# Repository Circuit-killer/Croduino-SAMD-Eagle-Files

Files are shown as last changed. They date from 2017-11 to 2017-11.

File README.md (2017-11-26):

# Croduino SAMD Eagle Files
## Image
will be available soon

## Description and details
Arduino compatible board based on ATSAMD21G18J with native USB. 

## Repository content
This repo contains Cadsoft Eagle .sch and .brd files for Croduino SAMD board. It also contains schematic in .pdf created from .sch Eagle file. 
Files have been arranged into folders for navigating between different versions of board. 
Tip: layer 200 shows top silkscreen and layer 208 should be bottom silkscreen. tParts and bParts layers are not used in actual PCB. 

## Docs
- available soon

## Board versions
- v1.0 - inital published version 

## License info
This product is open-source. Yay!
For any tech questions, contact us at techsupport@e-radionica.com
If you find an Issue, please open one at GitHub. If you can improve our product, fork us.

e-radionica.com Team.

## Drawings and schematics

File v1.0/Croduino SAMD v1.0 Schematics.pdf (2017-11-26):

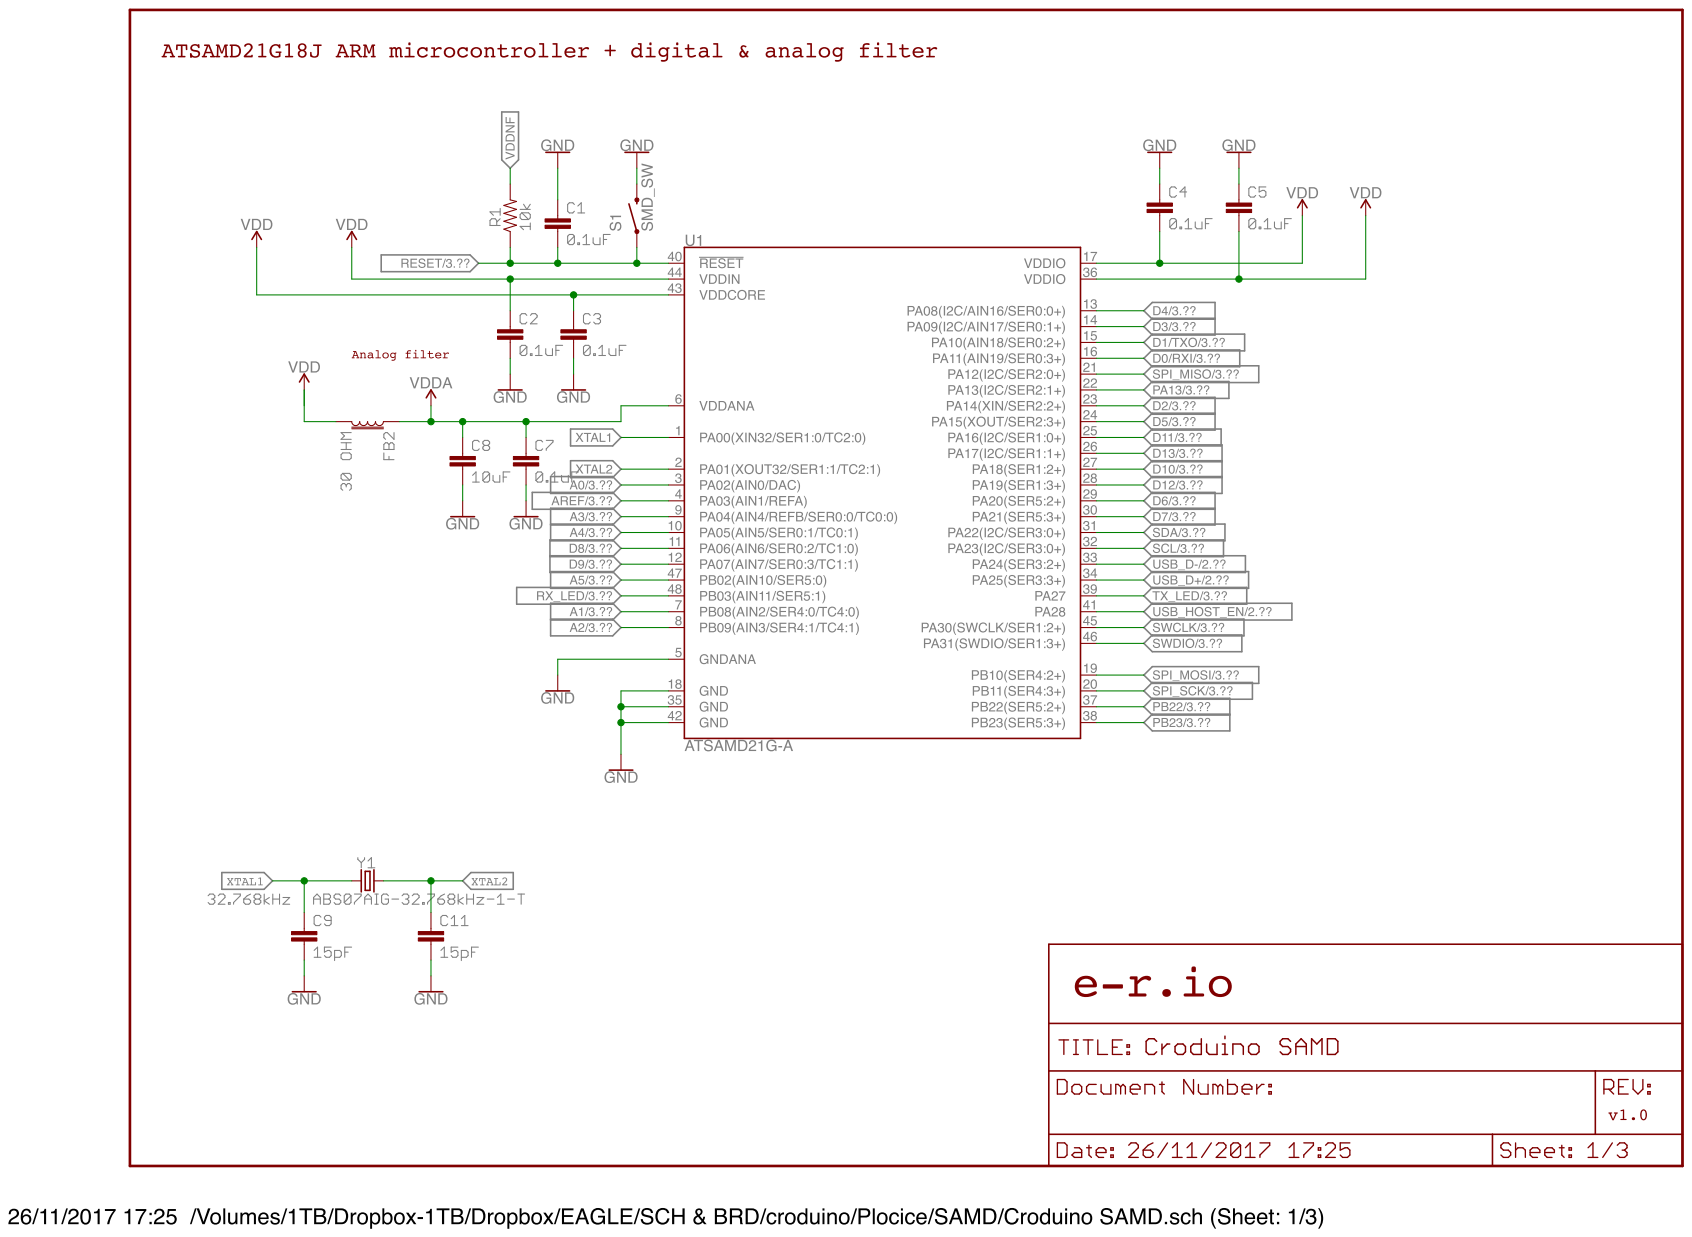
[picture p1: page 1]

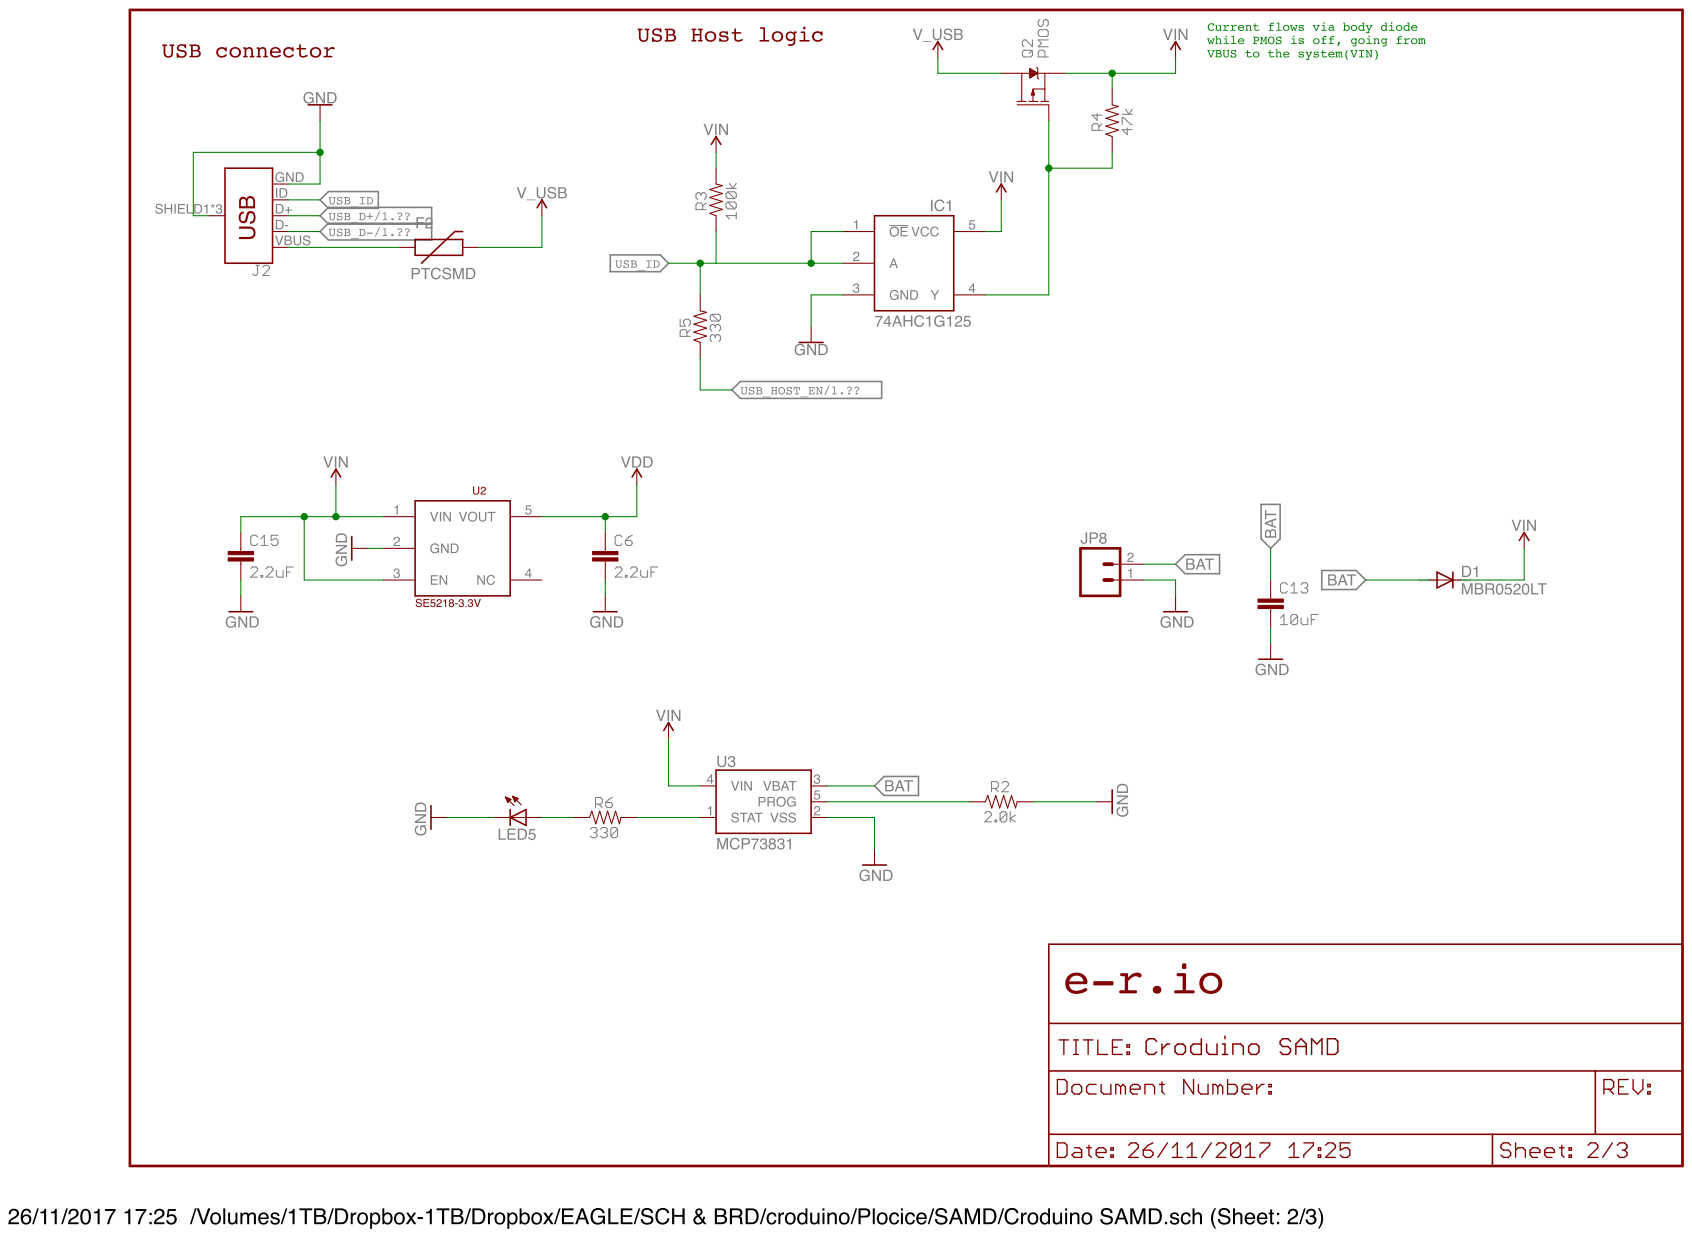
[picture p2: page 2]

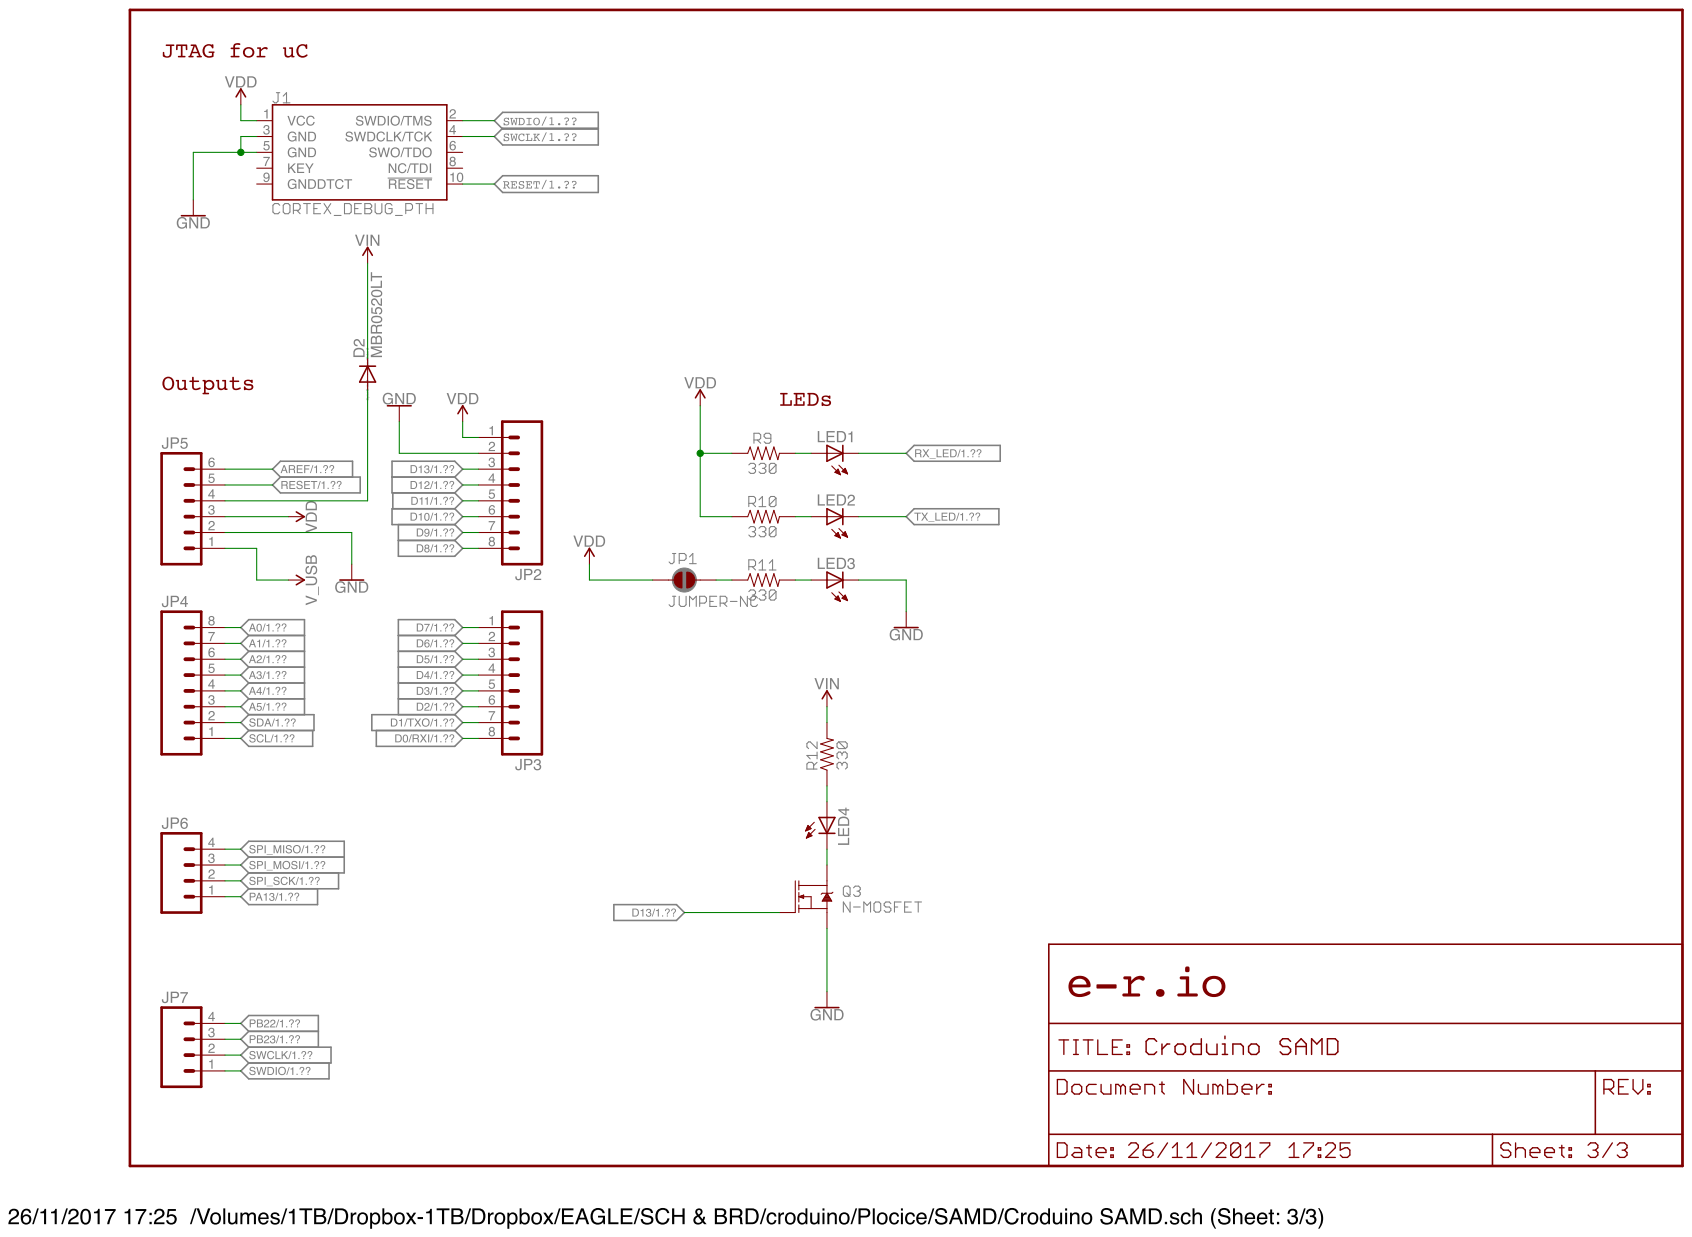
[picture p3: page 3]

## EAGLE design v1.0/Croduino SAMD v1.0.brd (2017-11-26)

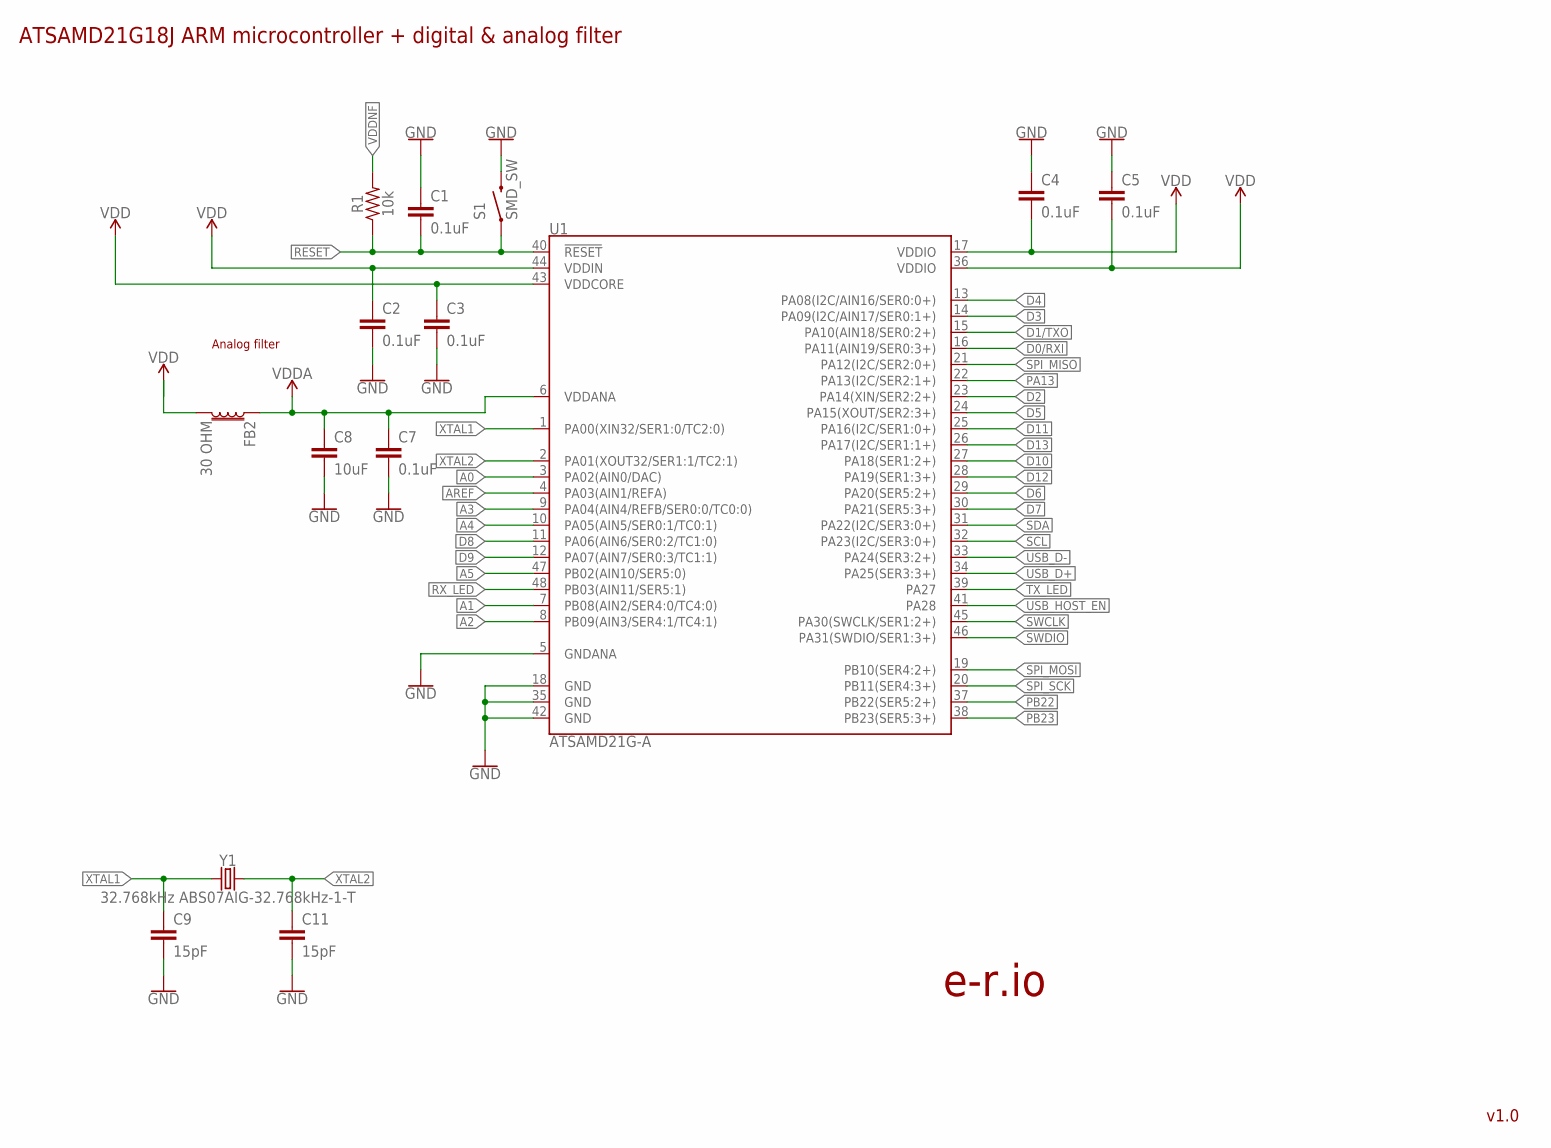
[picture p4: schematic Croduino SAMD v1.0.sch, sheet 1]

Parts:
C1, C2, C3, C4, C5, C7: 0.1uF; 0603
C8: 10uF; 1206
C9, C11: 15pF; 0603
FB2: 30 OHM; 0603
R1: 10k; 0603
S1: SMD_SW; TACTILE_SWITCH_SMD
U1: ATSAMD21G-A; TQFP-48
Y1: 32.768kHz ABS07AIG-32.768kHz-1-T; CRYSTAL-SMD-3.2X1.5MM

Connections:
A0: U1.3 (PA02(AIN0/DAC)); also elsewhere on the board
A1: U1.7 (PB08(AIN2/SER4:0/TC4:0)); also elsewhere on the board
A2: U1.8 (PB09(AIN3/SER4:1/TC4:1)); also elsewhere on the board
A3: U1.9 (PA04(AIN4/REFB/SER0:0/TC0:0)); also elsewhere on the board
A4: U1.10 (PA05(AIN5/SER0:1/TC0:1)); also elsewhere on the board
A5: U1.47 (PB02(AIN10/SER5:0)); also elsewhere on the board
AREF: U1.4 (PA03(AIN1/REFA)); also elsewhere on the board
D0/RXI: U1.16 (PA11(AIN19/SER0:3+)); also elsewhere on the board
D1/TXO: U1.15 (PA10(AIN18/SER0:2+)); also elsewhere on the board
D2: U1.23 (PA14(XIN/SER2:2+)); also elsewhere on the board
D3: U1.14 (PA09(I2C/AIN17/SER0:1+)); also elsewhere on the board
D4: U1.13 (PA08(I2C/AIN16/SER0:0+)); also elsewhere on the board
D5: U1.24 (PA15(XOUT/SER2:3+)); also elsewhere on the board
D6: U1.29 (PA20(SER5:2+)); also elsewhere on the board
D7: U1.30 (PA21(SER5:3+)); also elsewhere on the board
D8: U1.11 (PA06(AIN6/SER0:2/TC1:0)); also elsewhere on the board
D9: U1.12 (PA07(AIN7/SER0:3/TC1:1)); also elsewhere on the board
D10: U1.27 (PA18(SER1:2+)); also elsewhere on the board
D11: U1.25 (PA16(I2C/SER1:0+)); also elsewhere on the board
D12: U1.28 (PA19(SER1:3+)); also elsewhere on the board
D13: U1.26 (PA17(I2C/SER1:1+)); also elsewhere on the board
GND: C1.1, C2.2, C3.2, C4.1, C5.1, C7.2, C8.2, C9.2, C11.2, S1.3 (2), U1.5 (GNDANA), U1.18 (GND), U1.35 (GND), U1.42 (GND); also elsewhere on the board
PA13: U1.22 (PA13(I2C/SER2:1+)); also elsewhere on the board
PB22: U1.37 (PB22(SER5:2+)); also elsewhere on the board
PB23: U1.38 (PB23(SER5:3+)); also elsewhere on the board
RESET: C1.2, R1.1, S1.1, U1.40 (!RESET!); also elsewhere on the board
RX_LED: U1.48 (PB03(AIN11/SER5:1)); also elsewhere on the board
SCL: U1.32 (PA23(I2C/SER3:0+)); also elsewhere on the board
SDA: U1.31 (PA22(I2C/SER3:0+)); also elsewhere on the board
SPI_MISO: U1.21 (PA12(I2C/SER2:0+)); also elsewhere on the board
SPI_MOSI: U1.19 (PB10(SER4:2+)); also elsewhere on the board
SPI_SCK: U1.20 (PB11(SER4:3+)); also elsewhere on the board
SWCLK: U1.45 (PA30(SWCLK/SER1:2+)); also elsewhere on the board
SWDIO: U1.46 (PA31(SWDIO/SER1:3+)); also elsewhere on the board
TX_LED: U1.39 (PA27); also elsewhere on the board
USB_D+: U1.34 (PA25(SER3:3+)); also elsewhere on the board
USB_D-: U1.33 (PA24(SER3:2+)); also elsewhere on the board
USB_HOST_EN: U1.41 (PA28); also elsewhere on the board
VDD: C2.1, C3.1, C4.2, C5.2, FB2.2, U1.17 (VDDIO), U1.36 (VDDIO), U1.43 (VDDCORE), U1.44 (VDDIN); also elsewhere on the board
VDDA: C7.1, C8.1, FB2.1, U1.6 (VDDANA)
VDDNF: R1.2
XTAL1: C9.1, U1.1 (PA00(XIN32/SER1:0/TC2:0)), Y1.P$1 (1)
XTAL2: C11.1, U1.2 (PA01(XOUT32/SER1:1/TC2:1)), Y1.P$2 (2)

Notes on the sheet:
Analog filter
ATSAMD21G18J ARM microcontroller + digital & analog filter
e-r.io
v1.0

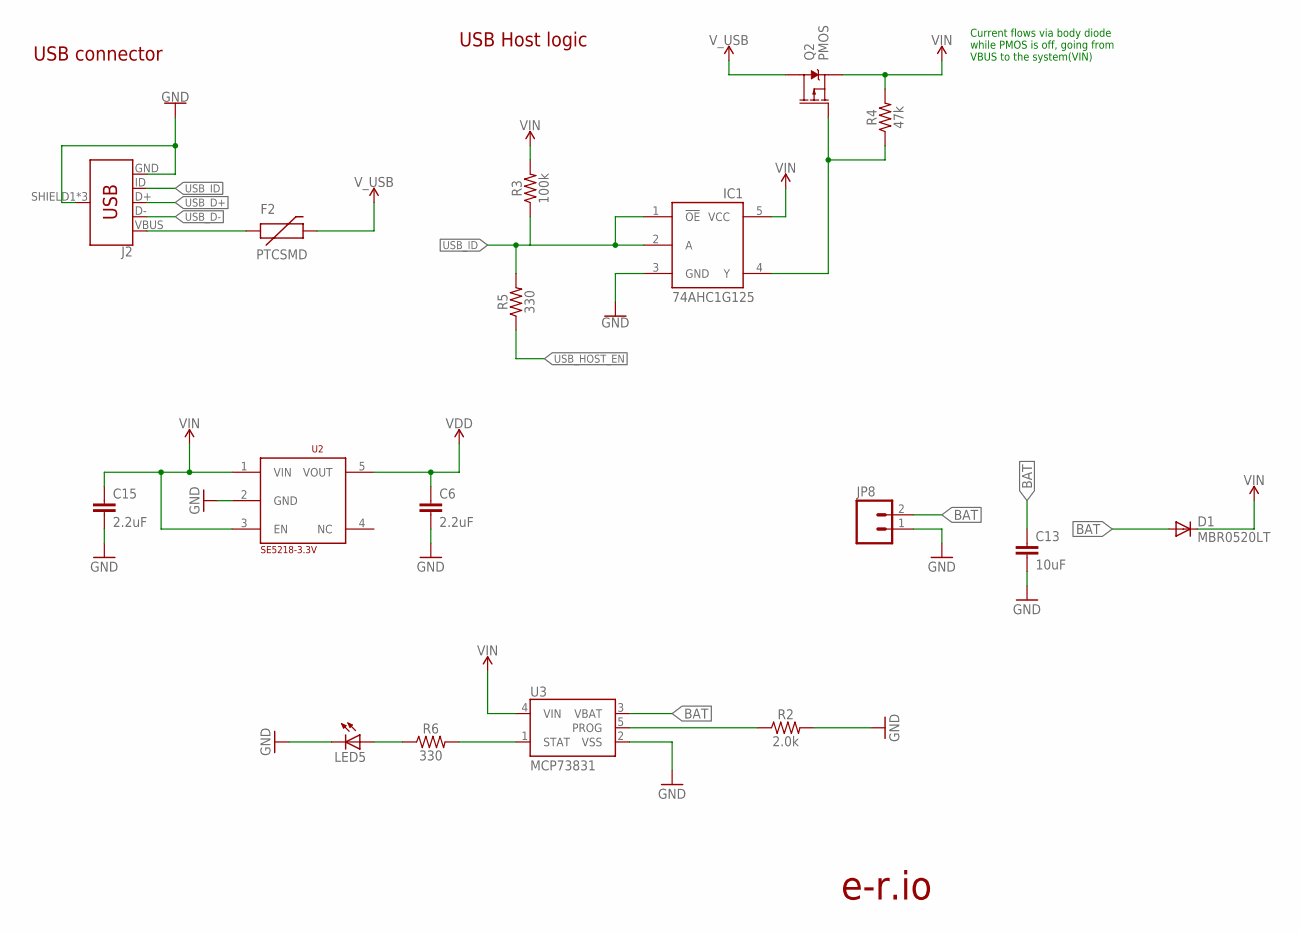
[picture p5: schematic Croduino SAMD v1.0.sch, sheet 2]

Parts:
C6, C15: 2.2uF; 0603
C13: 10uF; 1206
D1: MBR0520LT; SOD123
F2: PTCSMD; PTC-1206
IC1: 74AHC1G125; SOT23-5L
J2: USB_MICRO-BREDUCED_PASTE; USB-B-MICRO-SMD_RED_PASTE
JP8: M02-JST-2MM-SMT; JST-2-SMD
LED5: LEDCHIPLED_0805; CHIPLED_0805
Q2: PMOS; SOT23-3
R2: 2.0k; 0603
R3: 100k; 0603
R4: 47k; 0603
R5, R6: 330; 0603
U2: SE5218-3.3V; SOT23-5
U3: MCP73831; SOT23-5

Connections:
BAT: C13.1, D1.A, JP8.2, U3.3 (VBAT)
GND: C6.2, C13.2, C15.2, IC1.3 (GND), J2.GND, J2.SHIELD1 (SHIELD), J2.SHIELD2 (SHIELD), J2.SHIELD3 (SHIELD), JP8.1, LED5.C, R2.2, U2.2 (GND), U3.2 (VSS); also elsewhere on the board
unnamed: R6.2, U3.1 (STAT)
unnamed: F2.1, J2.VBUS
unnamed: IC1.4 (Y), Q2.1 (G), R4.1
unnamed: LED5.A, R6.1
unnamed: R2.1, U3.5 (PROG)
USB_D+: J2.D+; also elsewhere on the board
USB_D-: J2.D-; also elsewhere on the board
USB_HOST_EN: R5.1; also elsewhere on the board
USB_ID: IC1.1 (!OE), IC1.2 (A), J2.ID, R3.1, R5.2
VDD: C6.1, U2.5 (VOUT); also elsewhere on the board
VIN: C15.1, D1.C, IC1.5 (VCC), Q2.2 (S), R3.2, R4.2, U2.1 (VIN), U2.3 (EN), U3.4 (VIN); also elsewhere on the board
V_USB: F2.2, Q2.3 (D); also elsewhere on the board

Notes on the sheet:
Current flows via body diode while PMOS is off, going from VBUS to the system(VIN)
USB connector
USB Host logic
e-r.io

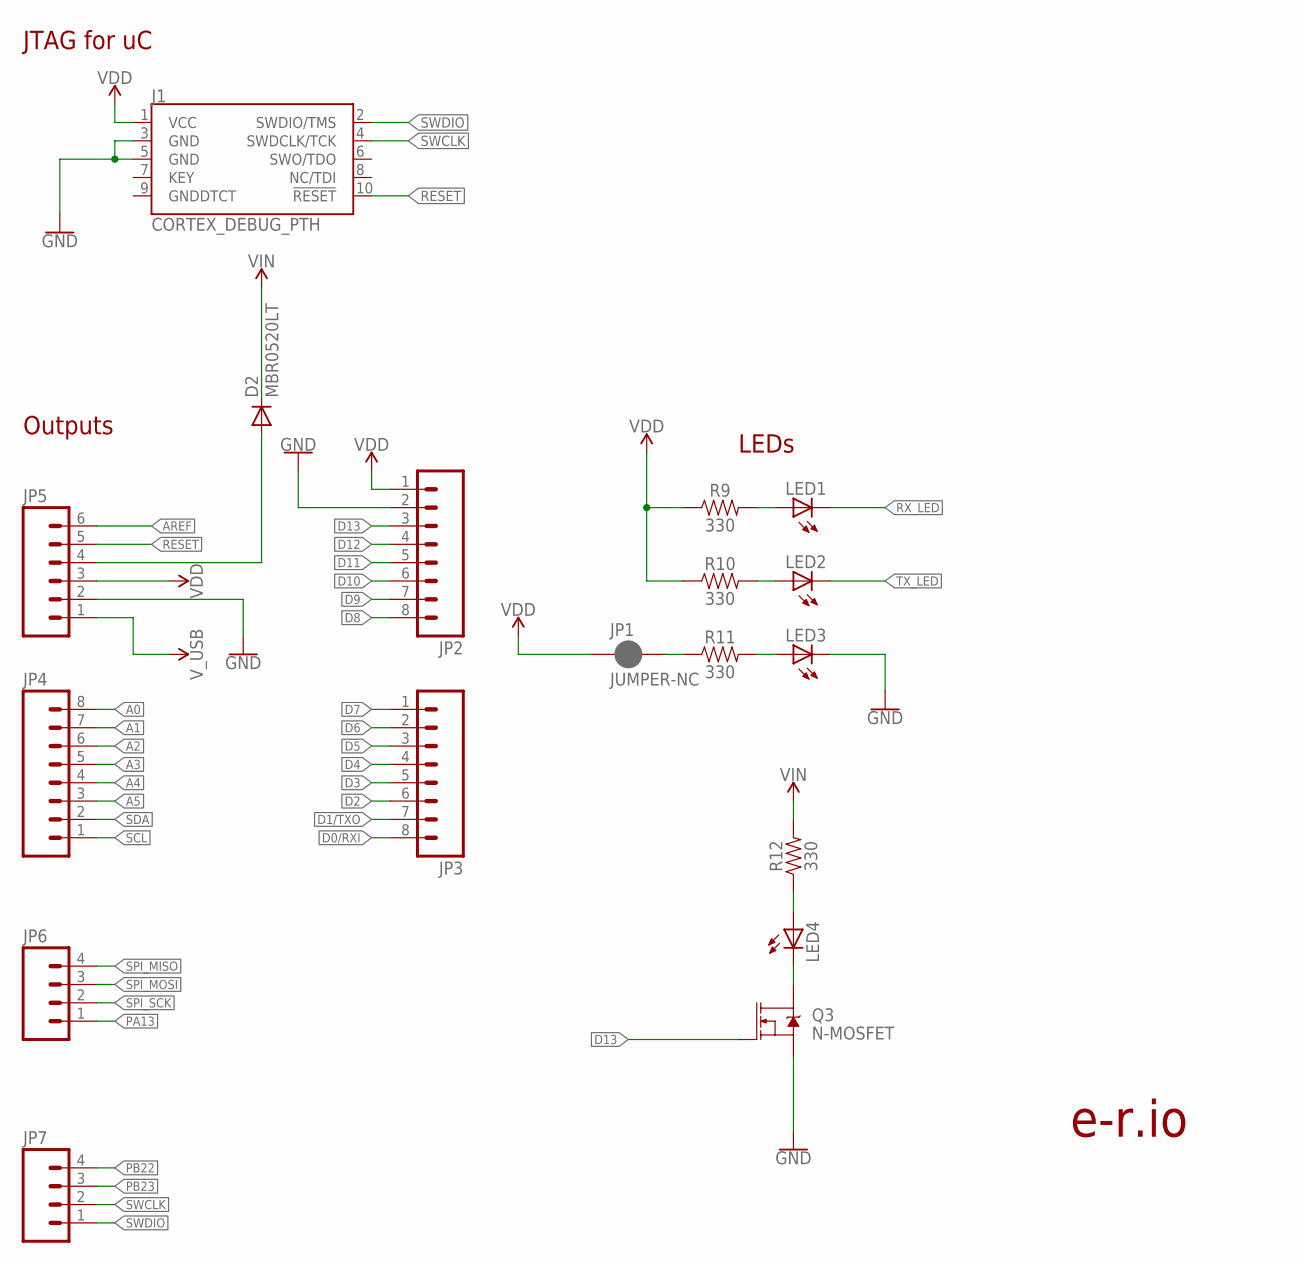
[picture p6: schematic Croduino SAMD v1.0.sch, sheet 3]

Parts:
D2: MBR0520LT; SOD123
J1: CORTEX_DEBUG_PTH; 2X5-PTH-1.27MM
JP1: JUMPER-NC; SMT-JUMPER_2_NC_PASTE_NO-SILK
JP2, JP3, JP4: M081X08; 1X08
JP5: M06SIP; 1X06
JP6, JP7: M04PTH; 1X04
LED1, LED2, LED3, LED4: LEDCHIPLED_0805; CHIPLED_0805
Q3: N-MOSFET; SOT23-3
R9, R10, R11, R12: 330; 0603

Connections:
A0: JP4.8; also elsewhere on the board
A1: JP4.7; also elsewhere on the board
A2: JP4.6; also elsewhere on the board
A3: JP4.5; also elsewhere on the board
A4: JP4.4; also elsewhere on the board
A5: JP4.3; also elsewhere on the board
AREF: JP5.6; also elsewhere on the board
D0/RXI: JP3.8; also elsewhere on the board
D1/TXO: JP3.7; also elsewhere on the board
D2: JP3.6; also elsewhere on the board
D3: JP3.5; also elsewhere on the board
D4: JP3.4; also elsewhere on the board
D5: JP3.3; also elsewhere on the board
D6: JP3.2; also elsewhere on the board
D7: JP3.1; also elsewhere on the board
D8: JP2.8; also elsewhere on the board
D9: JP2.7; also elsewhere on the board
D10: JP2.6; also elsewhere on the board
D11: JP2.5; also elsewhere on the board
D12: JP2.4; also elsewhere on the board
D13: JP2.3, Q3.1 (G); also elsewhere on the board
GND: J1.3 (GND), J1.5 (GND), JP2.2, JP5.2, LED3.C, Q3.2 (S); also elsewhere on the board
unnamed: JP1.2, R11.1
unnamed: LED4.A, R12.1
unnamed: D2.A, JP5.4
unnamed: LED3.A, R11.2
unnamed: LED2.A, R10.2
unnamed: LED1.A, R9.2
unnamed: LED4.C, Q3.3 (D)
PA13: JP6.1; also elsewhere on the board
PB22: JP7.4; also elsewhere on the board
PB23: JP7.3; also elsewhere on the board
RESET: J1.10 (!RESET), JP5.5; also elsewhere on the board
RX_LED: LED1.C; also elsewhere on the board
SCL: JP4.1; also elsewhere on the board
SDA: JP4.2; also elsewhere on the board
SPI_MISO: JP6.4; also elsewhere on the board
SPI_MOSI: JP6.3; also elsewhere on the board
SPI_SCK: JP6.2; also elsewhere on the board
SWCLK: J1.4 (SWDCLK/TCK), JP7.2; also elsewhere on the board
SWDIO: J1.2 (SWDIO/TMS), JP7.1; also elsewhere on the board
TX_LED: LED2.C; also elsewhere on the board
VDD: J1.1 (VCC), JP1.1, JP2.1, JP5.3, R9.1, R10.1; also elsewhere on the board
VIN: D2.C, R12.2; also elsewhere on the board
V_USB: JP5.1; also elsewhere on the board

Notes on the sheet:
JTAG for uC
Outputs
LEDs
e-r.io

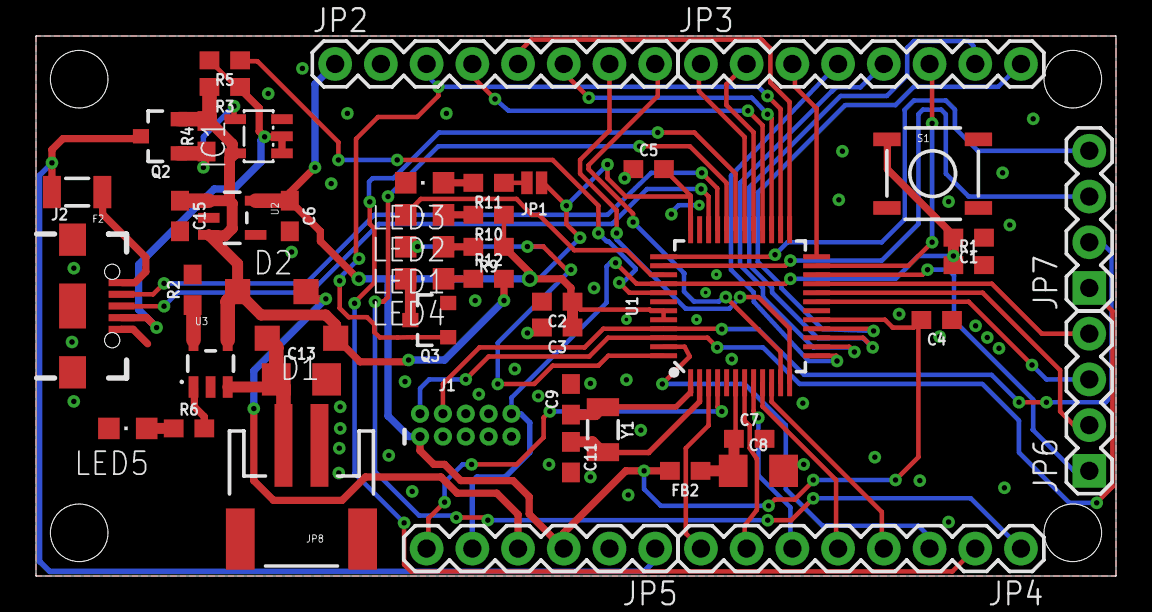
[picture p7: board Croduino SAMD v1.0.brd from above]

Board: 2 copper layers, 60.0 x 30.0 mm, 60 parts (1 on the bottom side), 58 nets.

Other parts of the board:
U$1: SAMD-GRAFIKA
U$2: LOGO-4MM
U$3: OSH-3MM
U$4: E-R.IO-3MM
U$8: MADE-IN-CROATIA-5MM
U$9: LUDI-LOGO-24MM
U$10: SAMD-BACK
U$11: OSH-BACK-6MM
U$12: E-R.IO-6MM
U$13: LOGO-BACK-6MM
U$14: E-R.IO-BACK-12MM

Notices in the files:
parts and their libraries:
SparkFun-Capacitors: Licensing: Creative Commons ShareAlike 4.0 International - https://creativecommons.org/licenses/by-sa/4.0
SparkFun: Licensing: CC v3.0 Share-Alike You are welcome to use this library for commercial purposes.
